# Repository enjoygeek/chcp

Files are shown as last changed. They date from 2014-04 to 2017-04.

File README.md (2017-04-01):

chcp
====

PoE powered, IPv6 Central Heating Control Panel

Block Diagram

Photo of circuit board:

Assembled circuit board

More photos in this gallery on Flickr:
https://www.flickr.com/photos/njh/sets/72157648035750106/

ATMEGA328 Pin Mapping
----------------------

| Pin | Port | Arduino | Function |
|-----|---|---|---|
| 1 | RST# | | |
| 2 | D0 | D0 | Serial RX |
| 3 | D1 | D1 | Serial TX |
| 4 | D2 | D2 | |
| 5 | D3 | D3 | LCD LIGHT |
| 6 | D4 | D4 | |
| 7 | VCC  | | |
| 8 | GND  | | |
| 9 | CLK  | | |
| 10  | CLK  | | |
| 11  | D5 | D5 | Push Button |
| 12  | D6 | D6 | Red LED |
| 13  | D7 | D7 | Ethernet SS |
| 14  | B0 | D8 | LCD RESET |
| 15  | B1 | D9 | LCD SS |
| 16  | B2 | D10 | LCD DC |
| 17  | B3 | D11 | SPI MOSI |
| 18  | B4 | D12 | SPI MISO |
| 19  | B5 | D13 | SPI SCLK |
| 20  | VCC  | | |
| 21  | Aref | | |
| 22  | GND  | | |
| 23  | C0 | A0 | |
| 24  | C1 | A1 | |
| 25  | C2 | A2 | |
| 26  | C3 | A3 | |
| 27  | C4 | A4 | I2C SDA |
| 28  | C5 | A5 | I2C SCL |

PoE Pin Mapping
---------------

| RJ45 | IN28J60 | PEM1300 |
|---|---|---|
| 1+2  | POE+1 | VA1 |
| 3+6  | POE-1 | VA2 |
| 4+5  | POE-2 | VB1 |
| 7+8  | POE+2 | VB2 |

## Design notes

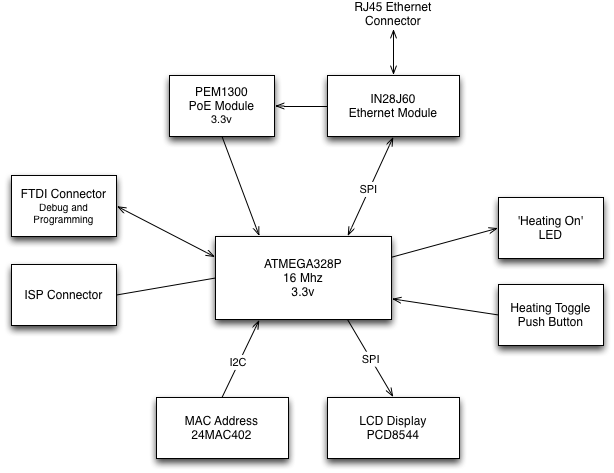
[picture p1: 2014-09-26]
block-diagram.png

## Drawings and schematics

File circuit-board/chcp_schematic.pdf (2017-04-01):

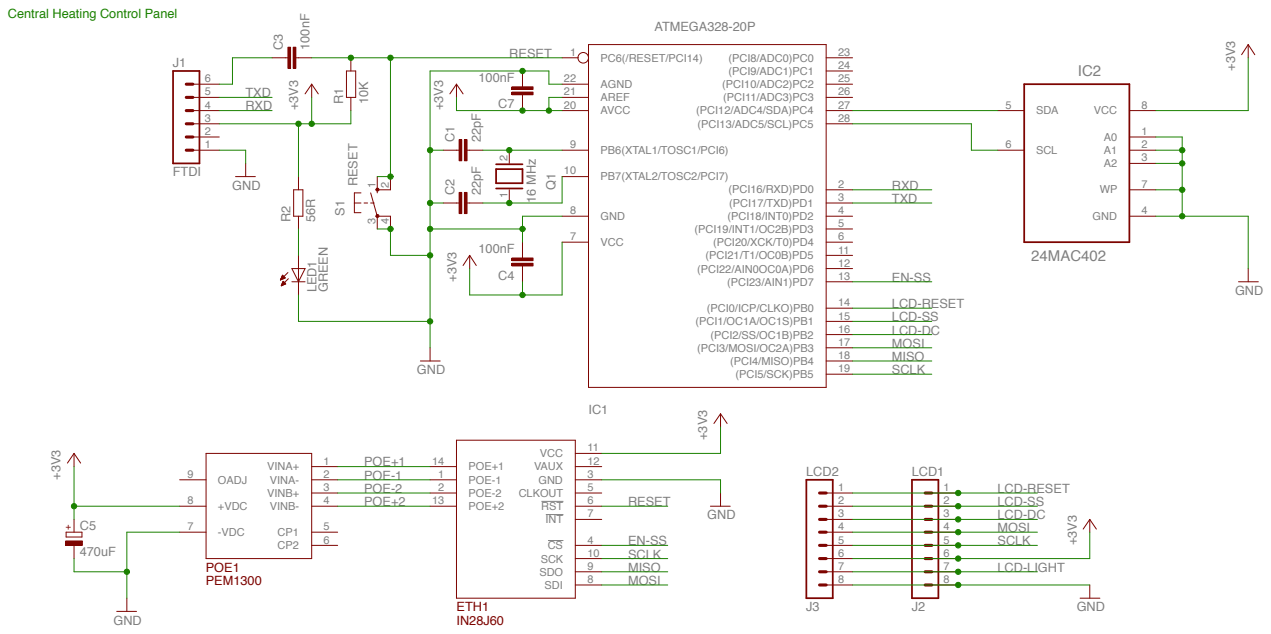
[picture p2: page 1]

Central Heating Control Panel

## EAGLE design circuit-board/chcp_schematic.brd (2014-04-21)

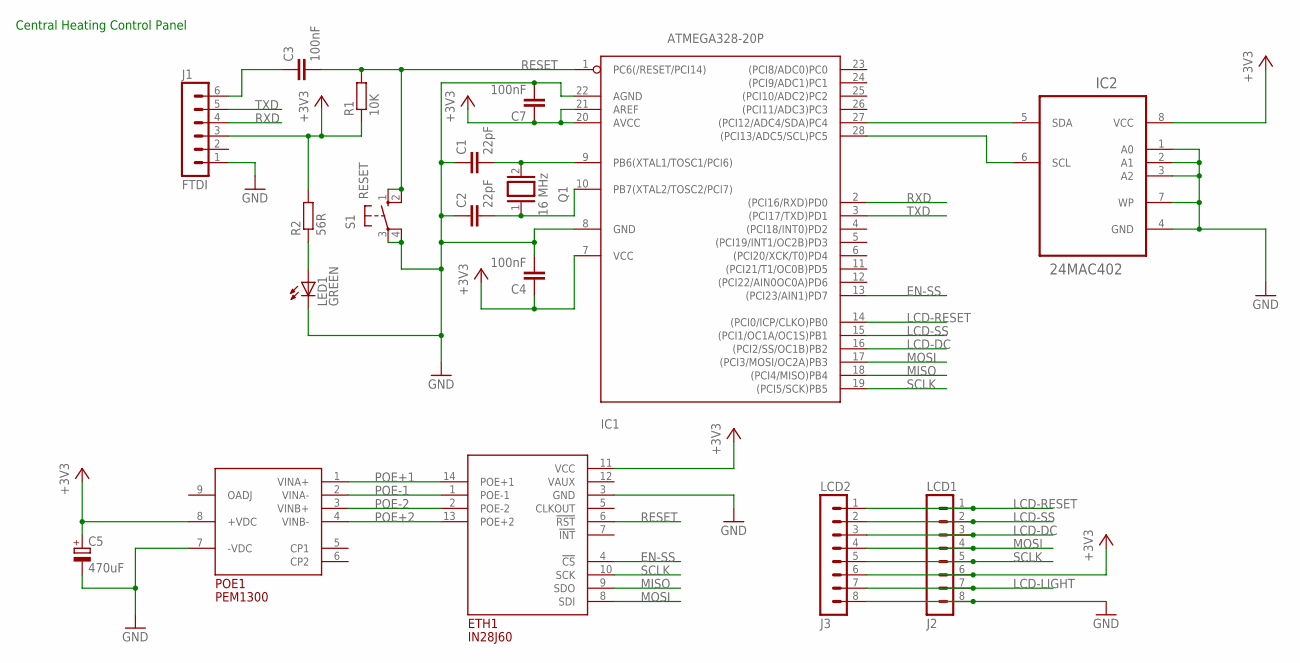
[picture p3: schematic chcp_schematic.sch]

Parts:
C1, C2: 22pF; C025-024X044
C3, C4, C7: 100nF; C025-024X044
C5: 470uF; E2,5-5
ETH1: IN28J60; DIL
IC1: ATMEGA328-20P; DIL28-3
IC2: 24MAC402; PDIP
J1: FTDI; MA06-1
J2: LCD1; MA08-1
J3: LCD2; MA08-1
LED1: GREEN; LED3MM
POE1: PEM1300; SIL
Q1: 16 MHz; QS
R1: 10K; 0204/7
R2: 56R; 0204/7
S1: RESET; B3F-10XX

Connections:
+3V3: C4.1, C5.+, C7.1, ETH1.11 (VCC), IC1.7 (VCC), IC1.20 (AVCC), IC1.21 (AREF), IC2.8 (VCC), J1.3, J2.6, J3.6, POE1.8 (+VDC), R1.1, R2.2
EN-SS: ETH1.4 (!CS!), IC1.13 ((PCI23/AIN1)PD7)
GND: C1.1, C2.1, C4.2, C5.-, C7.2, ETH1.3 (GND), IC1.8 (GND), IC1.22 (AGND), IC2.1 (A0), IC2.2 (A1), IC2.3 (A2), IC2.4 (GND), IC2.7 (WP), J1.1, J2.8, J3.8, LED1.K (C), POE1.7 (-VDC), S1.3, S1.4 (P1)
LCD-DC: IC1.16 ((PCI2/SS/OC1B)PB2), J2.3, J3.3
LCD-LIGHT: J2.7, J3.7
LCD-RESET: IC1.14 ((PCI0/ICP/CLKO)PB0), J2.1, J3.1
LCD-SS: IC1.15 ((PCI1/OC1A/OC1S)PB1), J2.2, J3.2
MISO: ETH1.9 (SDO), IC1.18 ((PCI4/MISO)PB4)
MOSI: ETH1.8 (SDI), IC1.17 ((PCI3/MOSI/OC2A)PB3), J2.4, J3.4
unnamed: C2.2, IC1.10 (PB7(XTAL2/TOSC2/PCI7)), Q1.1
unnamed: IC1.27 ((PCI12/ADC4/SDA)PC4), IC2.5 (SDA)
unnamed: IC1.28 ((PCI13/ADC5/SCL)PC5), IC2.6 (SCL)
unnamed: C3.1, J1.6
unnamed: C1.2, IC1.9 (PB6(XTAL1/TOSC1/PCI6)), Q1.2
unnamed: LED1.A, R2.1
POE+1: ETH1.14 (POE+1), POE1.1 (VINA+)
POE+2: ETH1.13 (POE+2), POE1.4 (VINB-)
POE-1: ETH1.1 (POE-1), POE1.2 (VINA-)
POE-2: ETH1.2 (POE-2), POE1.3 (VINB+)
RESET: C3.2, ETH1.6 (!RST!), IC1.1 (PC6(/RESET/PCI14)), R1.2, S1.1 (S), S1.2 (S1)
RXD: IC1.2 ((PCI16/RXD)PD0), J1.4
SCLK: ETH1.10 (SCK), IC1.19 ((PCI5/SCK)PB5), J2.5, J3.5
TXD: IC1.3 ((PCI17/TXD)PD1), J1.5

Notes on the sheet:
Central Heating Control Panel

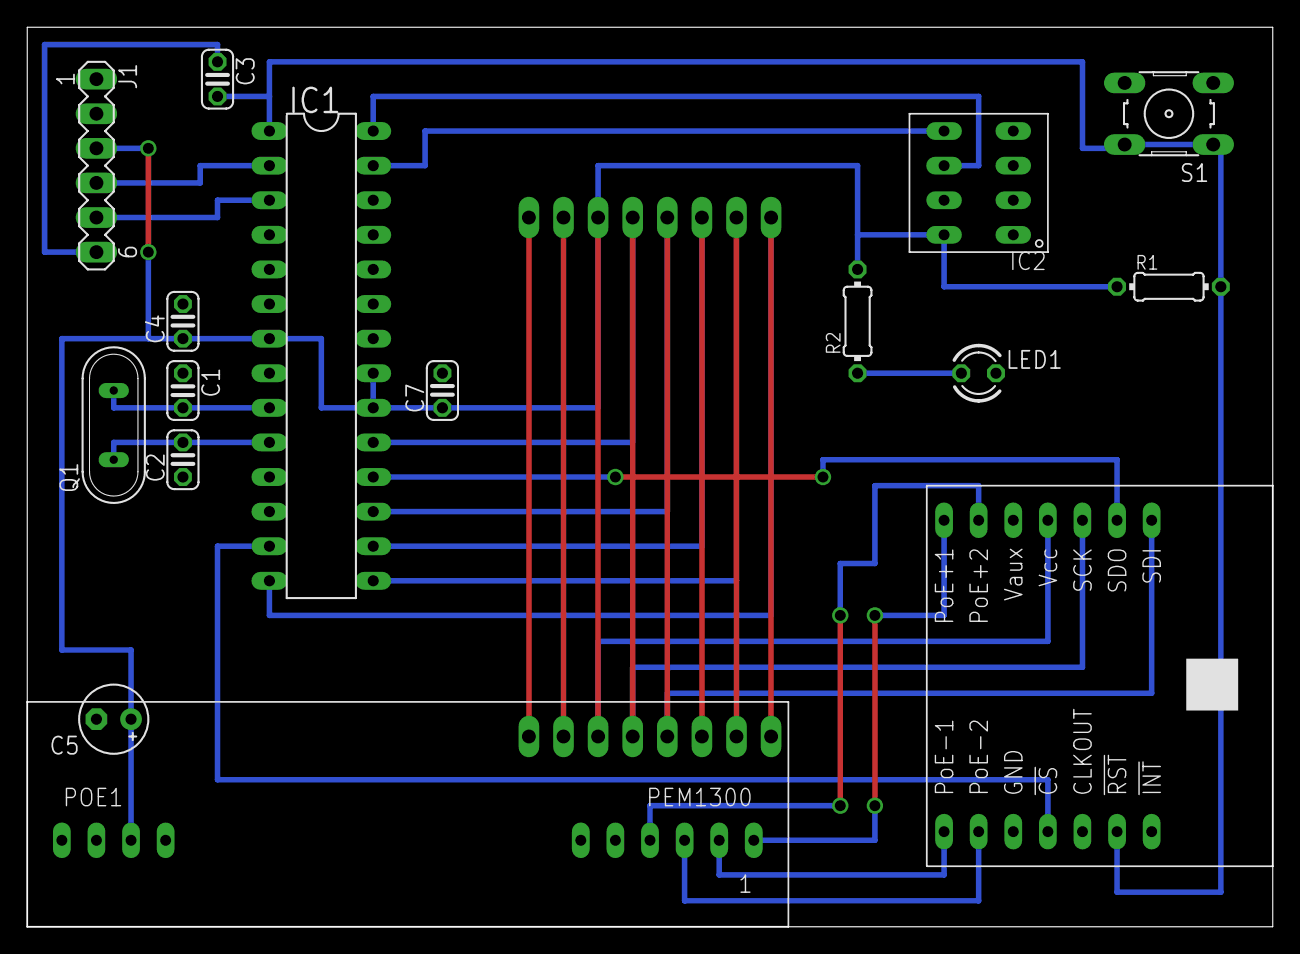
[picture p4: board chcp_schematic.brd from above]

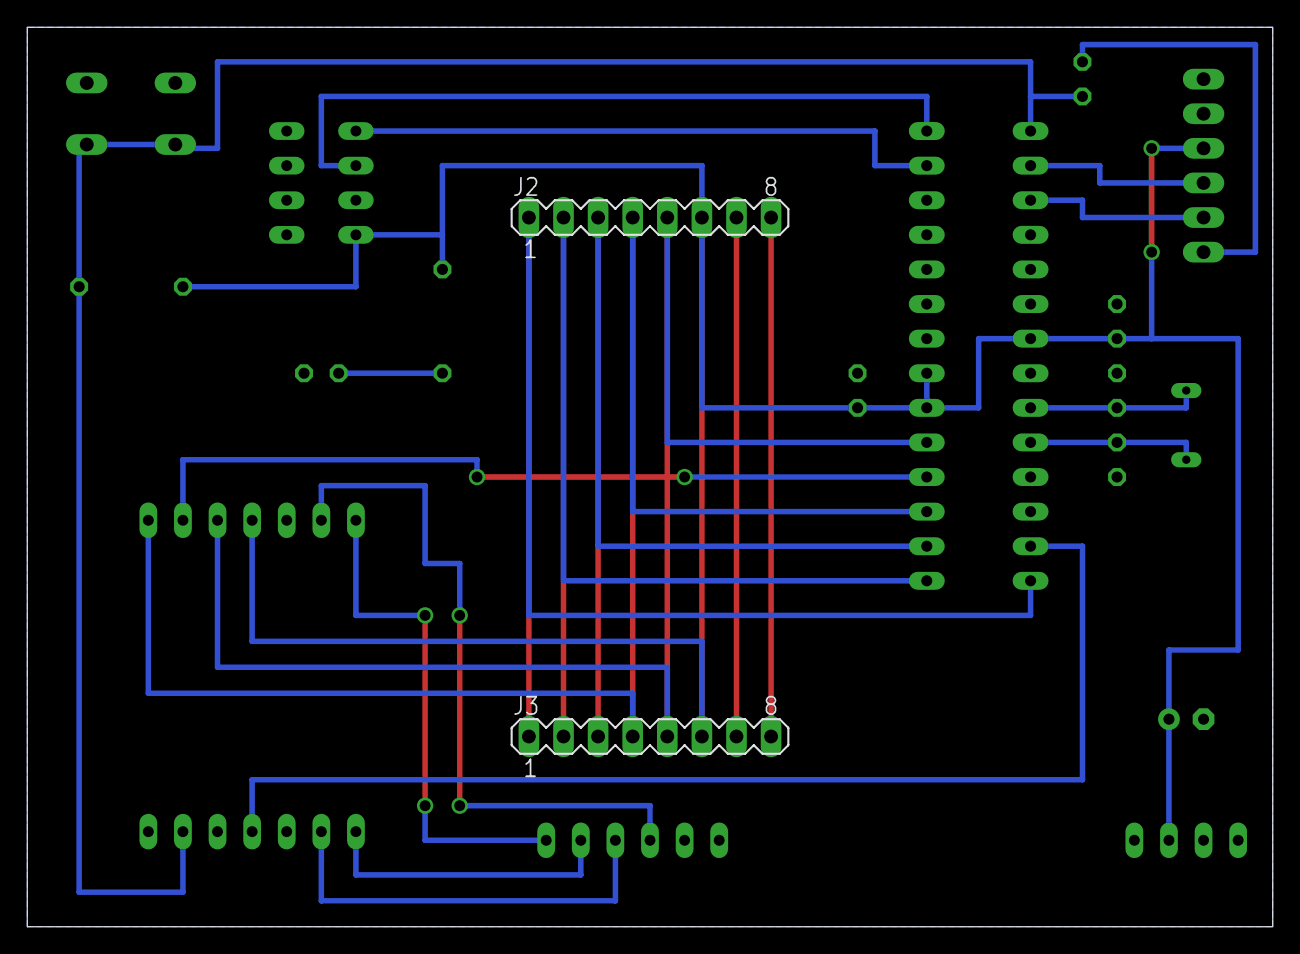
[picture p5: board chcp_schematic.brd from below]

Board: 2 copper layers, 91.4 x 66.0 mm, 18 parts (2 on the bottom side), 23 nets.

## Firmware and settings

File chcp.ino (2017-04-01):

/* 
 * IPv6 enabled Central Heating Control Panel
 * Copyright 2014-2017 Nicholas Humfrey
 *
 * Libary Dependencies:
 *   https://github.com/njh/ethersia
 *   https://github.com/snigelen/pcd8544
 *
 */

#include <Wire.h>
#include <EtherSia.h>
#include <pcd8544.h>

const uint8_t bitmap_on[3*60] PROGMEM = {
  0x00,0x00,0x00,0x00,0x00,0x00,0x00,0x00,0x80,0xc0,0xe0,0xf0,0xf0,0xf8,0xf8,
  0xf8,0xf8,0xf8,0xf8,0xf8,0xf8,0xf8,0xf8,0xf0,0xe0,0xe0,0xc0,0x00,0x00,0x00,
  0x00,0xf8,0xf8,0xf8,0xf8,0xf8,0xf8,0xf0,0xe0,0xc0,0x80,0x00,0x00,0x00,0x00,
  0x00,0xf8,0xf8,0xf8,0xf8,0xf8,0xf8,0x00,0x00,0x00,0x00,0x00,0x00,0x00,0x00,
  0x00,0x00,0x00,0x00,0x00,0x00,0x00,0xfe,0xff,0xff,0xff,0xff,0xff,0xc7,0x01,
  0x00,0x00,0x00,0x00,0x00,0x00,0x01,0xc7,0xff,0xff,0xff,0xff,0xff,0x7c,0x00,
  0x00,0xff,0xff,0xff,0xff,0xff,0xff,0x0f,0x1f,0x3f,0x7f,0xff,0xfe,0xfc,0xf8,
  0xf0,0xff,0xff,0xff,0xff,0xff,0xff,0x00,0x00,0x00,0x00,0x00,0x00,0x00,0x00,
  0x00,0x00,0x00,0x00,0x00,0x00,0x00,0x00,0x03,0x07,0x0f,0x1f,0x1f,0x3f,0x3f,
  0x3e,0x3e,0x3e,0x3e,0x3e,0x3e,0x3f,0x3f,0x1f,0x1f,0x0f,0x07,0x03,0x00,0x00,
  0x00,0x3f,0x3f,0x3f,0x3f,0x3f,0x3f,0x00,0x00,0x00,0x00,0x01,0x03,0x07,0x0f,
  0x1f,0x3f,0x3f,0x3f,0x3f,0x3f,0x3f,0x00,0x00,0x00,0x00,0x00,0x00,0x00,0x00,
};

const uint8_t bitmap_off[3*60] PROGMEM = {
  0x00,0x00,0x00,0x80,0xc0,0xe0,0xf0,0xf0,0xf8,0xf8,0xf8,0xf8,0xf8,0xf8,0xf8,
  0xf8,0xf8,0xf8,0xf0,0xe0,0xe0,0xc0,0x00,0x00,0x00,0x00,0x00,0xf8,0xf8,0xf8,
  0xf8,0xf8,0xf8,0x78,0x78,0x78,0x78,0x78,0x78,0x78,0x78,0x00,0x00,0x00,0xf8,
  0xf8,0xf8,0xf8,0xf8,0xf8,0x78,0x78,0x78,0x78,0x78,0x78,0x78,0x78,0x00,0x00,
  0x00,0x00,0xfe,0xff,0xff,0xff,0xff,0xff,0xc7,0x01,0x00,0x00,0x00,0x00,0x00,
  0x00,0x01,0xc7,0xff,0xff,0xff,0xff,0xff,0x7c,0x00,0x00,0x00,0xff,0xff,0xff,
  0xff,0xff,0xff,0x7c,0x7c,0x7c,0x7c,0x7c,0x7c,0x7c,0x7c,0x00,0x00,0x00,0xff,
  0xff,0xff,0xff,0xff,0xff,0x7c,0x7c,0x7c,0x7c,0x7c,0x7c,0x7c,0x7c,0x00,0x00,
  0x00,0x00,0x00,0x03,0x07,0x0f,0x1f,0x1f,0x3f,0x3f,0x3e,0x3e,0x3e,0x3e,0x3e,
  0x3e,0x3f,0x3f,0x1f,0x1f,0x0f,0x07,0x03,0x00,0x00,0x00,0x00,0x3f,0x3f,0x3f,
  0x3f,0x3f,0x3f,0x00,0x00,0x00,0x00,0x00,0x00,0x00,0x00,0x00,0x00,0x00,0x3f,
  0x3f,0x3f,0x3f,0x3f,0x3f,0x00,0x00,0x00,0x00,0x00,0x00,0x00,0x00,0x00,0x00,
};


#define BUTTON_PIN   5
#define RED_LED_PIN  6
#define ETH_SS_PIN   7
#define LCD_RST_PIN  8
#define LCD_SS_PIN   9
#define LCD_DC_PIN   10

#define DEBOUNCE_TIME 300

enum {
  STATE_UNKNOWN,
  STATE_OFF,
  STATE_ON,
  STATE_ERROR,
};

int state = STATE_UNKNOWN;    // the current state of the output pin
int buttonPrevious = LOW;     // the previous reading from the input pin
long buttonTime = 0;          // the last time the output pin was toggled

uint8_t serverIp[4] = {0,0,0,0};


// Create a pcd8544 object using hardware SPI
pcd8544 lcd(
  LCD_DC_PIN,
  LCD_RST_PIN,
  LCD_SS_PIN
);

// Ethernet and MAC address buffers
EtherSia_ENC28J60 ether(ETH_SS_PIN);
UDPSocket udp(ether, 5000);
static byte mymac[6];


void setup(void)
{
  // Setup LED and buttons
  pinMode(RED_LED_PIN, OUTPUT);
  pinMode(BUTTON_PIN, INPUT_PULLUP);

  // Clear the LCD
  lcd.begin();
  lcd.clear();
  lcd.gotoRc(0,0);

  lcd.println("Central");
  lcd.println("Heating");
  lcd.println("Control");
  lcd.println("Panel");

  // Setup IP networking
  startNetworking();
  delay(2000);

  // Update the LCD screen to current state
  updateDisplay();
}


void loop(void)
{
  // process packets
  ether.receivePacket();

  if (udp.havePacket()) {
      if (udp.payloadEquals("onn")) {
         state = STATE_ON;
      } else if (udp.payloadEquals("off")) {
         state = STATE_OFF;
      } else {
        state = STATE_ERROR;
      }

      updateDisplay();
  }

  // Check if button has gone from LOW to HIGH and stayed there
  int reading = digitalRead(BUTTON_PIN);
  if (reading == LOW && buttonPrevious == HIGH && millis() - buttonTime > DEBOUNCE_TIME) {
    const char* message = NULL;
    buttonTime = millis();

    if (state == STATE_ON) {
      message = "off";
    } else {
      message = "onn";
    }

    udp.send(message);
  }

  buttonPrevious = reading;
}


void updateDisplay()
{
  lcd.clear();
  lcd.gotoRc(0,0);
  lcd.println("    Central  ");
  lcd.println("    Heating  ");
  lcd.println();

  if (state == STATE_ON) {
    lcd.gotoRc(3, 12);
  	lcd.bitmap(bitmap_on, 3, 60);
    digitalWrite(RED_LED_PIN, HIGH);
  } else if (state == STATE_OFF) {
    lcd.gotoRc(3, 12);
  	lcd.bitmap(bitmap_off, 3, 60);
    digitalWrite(RED_LED_PIN, LOW);
  } else if (state == STATE_ERROR) {
    lcd.println("Error");
    digitalWrite(RED_LED_PIN, LOW);
  } else if (state == STATE_UNKNOWN) {
    lcd.println("Please wait.");
    digitalWrite(RED_LED_PIN, LOW);
  }
}


// Setup Ethetnet networking
void startNetworking()
{
  lcd.clear();
  lcd.gotoRc(0,0);

  // Start I2C communication and read MAC address
  Wire.begin();
  readMacAddress(0x0, mymac);
  lcd.println("MAC Address:");
  for (byte i = 0; i < 6; ++i) {
    lcd.print(mymac[i], HEX);
  }
  lcd.println();
  delay(2000);

  lcd.println("Setup ENC28J60");
  if (ether.begin(mymac)) {
    lcd.println("OK");
  } else {
    lcd.println("Fail");
    while (true);
  }

  // Address of the local NodeRED server
  udp.setRemoteAddress("fe80::ba27:ebff:fe13:bc65", 5000);
  udp.send("?");
}


// Function to read the MAC address from a AT24MAC402 EEPROM
//
// address: the 3-bit address assinged to the EEPROM (using the A0 A1 A2 pins)
// macaddr: a pointer to 6 bytes of memory
//
void readMacAddress(byte address, byte macaddr[]) {
  int i2c_address = 0x58 | address;

  // Tell the EEPROM where we would like to read from
  Wire.beginTransmission(i2c_address);
  Wire.write(0x9A); // Location of the EUI-48
  Wire.endTransmission();

  // Now read 6 bytes from that memory address
  Wire.requestFrom(i2c_address, 6);
  for(byte i=0; i<6; i++) {
    macaddr[i] = Wire.read();
  }
}

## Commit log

2014-03-09 Added work in progress of my Central Heating Control Panel schematic
    [chcp_schematic.sch]
2014-03-15 Created a block diagram of the circuit
2014-03-15 Created basic Arduino sketch
2014-04-21 Moved circuit board into sperate directory
    [chcp_schematic.sch]
2014-04-21 Made custom parts for the modules instead of using headers
    [chcp_schematic.sch]
2014-04-21 Removed the unnecessary capacitor connected to AREF
    [chcp_schematic.sch]
2014-04-21 Gave jumpers both names and values
    [chcp_schematic.sch]
2014-04-21 Finished laying out first version of the board
    [chcp_schematic.brd]
2014-04-21 Added 3mm Green Power LED
    [chcp_schematic.brd, chcp_schematic.sch]
2014-09-26 Added PoE pin mapping to README
2014-09-26 Added ATMEGA328 pin mapping to README
2014-09-27 Update README.md
    Added photo of board
2014-09-27 Update README.md
    Correct pin assignments
2014-09-27 Added Red LED and Push Button to the schematic
    [chcp_schematic.sch]
2014-09-27 Updated PIN numbers to match the new PCB board
2014-09-27 Changed button to use internal pull up resistor and be active LOW
2017-04-01 Added PDF of the schematic
